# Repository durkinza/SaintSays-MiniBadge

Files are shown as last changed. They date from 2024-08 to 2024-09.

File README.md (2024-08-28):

# SAINTSays Mini-Badge

<span style="font-size:0.8em;font-style:italic;">This badge is not made in affiliation with or endorced by the SAINTCON conference or the Utah SAINT organization</span>

This was my first time designing and producing a minibadge for SAINTCON (2024), so it may be a bit rough around the edges.

This repo contains the Code and KiCad file for the SAINTSays Mini-Badge.

## Programming the Badge

Compiling the code in the Arduino IDE for an ATTINY requires a package that supports the `Wire.h` library.

I found that the [ATTINYCore](https://github.com/SpenceKonde/ATTinyCore/blob/v2.0.0-devThis-is-the-head-submit-PRs-against-this/Installation.md) library works well for this. 
If you don't plan on using the I2C features, The [attiny](https://github.com/damellis/attiny) package can also be used for programming the badge. 

The badge has the AREF pins connected to the Mini-Badge headers using the [suggested connection method](https://github.com/lukejenkins/minibadge#prog): 

| Header| Pin |
|---|---|
| MISO  | Pin 3 |
| CLK | Pin 4 |
| MOSI  | Pin 5 |
| RESET | Pin 6 |

The power pin is wired to the 3.3v supply on Pin 7 and ground on Pin 8.

The Clock and SDA/SCL pins are also connected to the ATTiny. 
Be sure these Headers are not connected to external things when programming the badge. 

## Disabling I2C
If you don't plan on using the I2C features of the badbge, the code can be removed by commenting out the `#define USEI2C true` line near the top of the .ino file. 
This has the added benefit of making the compiled code a fair bit smaller too.

## Documentation

[How to solder the badge](https://zanedurk.in/soldering-the-saintsays-mini-badge/)

[How it's made](https://zanedurk.in/saintsays-mini-badge/)

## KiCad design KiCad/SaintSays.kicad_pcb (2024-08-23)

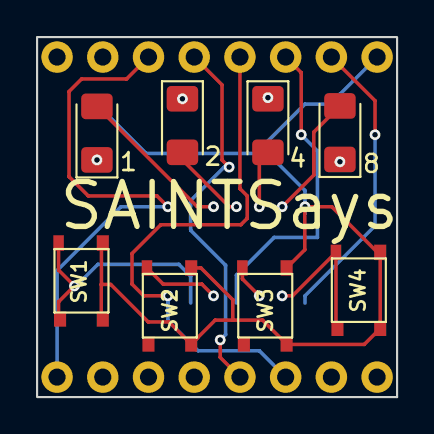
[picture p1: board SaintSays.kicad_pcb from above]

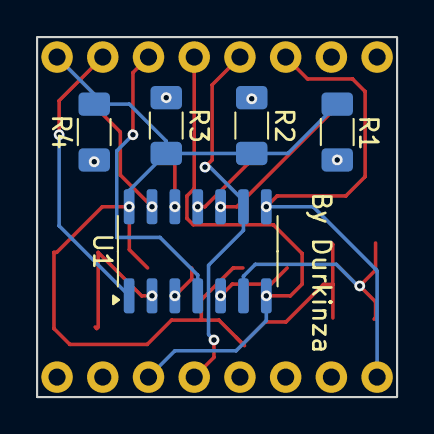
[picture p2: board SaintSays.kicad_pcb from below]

Board: 2 copper layers, 20.0 x 20.0 mm, 14 parts (5 on the bottom side), 18 nets.

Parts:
1, 2, 4, 8: LED; LED_1206_3216Metric_Pad1.42x1.75mm_HandSolder
MB1: MiniBadge_SAINTSays; MiniBadge_Full
R1, R2, R3, R4: R_US; R_1206_3216Metric_Pad1.30x1.75mm_HandSolder
SW1, SW2, SW3, SW4: SW_Push; SW_SPST_3x3-L
U1: ATtiny84A-SS; SOIC-14_3.9x8.7mm_P1.27mm

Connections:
unnamed: 1.2 (A), U1.10 (PA3)
unnamed: 1.1 (K), R1.1
unnamed: 2.2 (A), U1.11 (PA2)
unnamed: 2.1 (K), R2.1
unnamed: 4.2 (A), U1.12 (PA1)
unnamed: 4.1 (K), R3.1
unnamed: 8.2 (A), U1.13 (AREF/PA0)
unnamed: 8.1 (K), R4.1
unnamed: MB1.7 (+3V3), U1.1 (VCC)
unnamed: MB1.3 (MISO), MB1.9 (CLK), U1.8 (PA5)
unnamed: MB1.6 (CS), U1.4 (~RESET/PB3)
unnamed: MB1.5 (MOSI), MB1.14 (SDA), U1.7 (PA6)
unnamed: MB1.4 (SCK), MB1.13 (SCL), U1.9 (PA4)
unnamed: MB1.8 (GND), R1.2, R2.2, R3.2, R4.2, SW1.2, SW2.2, SW3.2, SW4.2, U1.14 (GND)
unnamed: SW1.1, U1.6 (PA7)
unnamed: SW2.1, U1.5 (PB2)
unnamed: SW4.1, U1.2 (XTAL1/PB0)
unnamed: SW3.1, U1.3 (XTAL2/PB1)

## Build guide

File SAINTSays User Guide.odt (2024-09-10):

SAINTSays By Durkinza | MODES The Badge has 4 modes: Sleep, Game, Settings, and Party When first booted, the badge goes into Sleep Mode. | SLEEP MODE Sleep Mode is the default mode of this badge. After your first game, this mode will display your score in binary on the LEDs (in Little Endian). (A new badge will have a score of 0, so no LEDS on)
GAME MODE Game Mode can be entered by pushing any individual button while in Sleep Mode. Press the outside buttons simultaneously to return to Sleep Mode. If nothing is pressed for 60 seconds, the badge will return to Sleep Mode. | GAME MODE Cont’d. The game is Simon Says, where the badge will flash a pattern of LEDs and wait for you to repeat the pattern. Each successful round will increase the pattern's length. When an incorrect pattern is entered, the badge will flash. If you get a new high score, the badge will save this locally to its EEPROM. | SETTINGS MODE To enter Settings Mode, press the outside buttons simultaneously while in Sleep Mode. Do this again to return to Sleep Mode. There are 4 settings that can be toggled: 1: Show scoreboard in Sleep Mode. 2: ! Fast Mode. (Light speed) 3: ! Chaotic Mode (Hard Mode; no repetitions) 4: ! Boot to Party Mode

SAINTSays By Durkinza | MODES The Badge has 4 modes: Sleep, Game, Settings, and Party When first booted, the badge goes into Sleep Mode. | SLEEP MODE Sleep Mode is the default mode of this badge. After your first game, this mode will display your score in binary on the LEDs (in Little Endian). (A new badge will have a score of 0, so no LEDS on)
GAME MODE Game Mode can be entered by pushing any individual button while in Sleep Mode. Press the outside buttons simultaneously to return to Sleep Mode. If nothing is pressed for 60 seconds, the badge will return to Sleep Mode. | GAME MODE Cont’d. The game is Simon Says, where the badge will flash a pattern of LEDs and wait for you to repeat the pattern. Each successful round will increase the pattern's length. When an incorrect pattern is entered, the badge will flash. If you get a new high score, the badge will save this locally to its EEPROM. | SETTINGS MODE To enter Settings Mode, press the outside buttons simultaneously while in Sleep Mode. Do this again to return to Sleep Mode. There are 4 settings that can be toggled: 1: Show scoreboard in Sleep Mode. 2: ! Fast Mode. (Light speed) 3: ! Chaotic Mode (Hard Mode; no repetitions) 4: ! Boot to Party Mode

SAINTSays By Durkinza | MODES The Badge has 4 modes: Sleep, Game, Settings, and Party When first booted, the badge goes into Sleep Mode. | SLEEP MODE Sleep Mode is the default mode of this badge. After your first game, this mode will display your score in binary on the LEDs (in Little Endian). (A new badge will have a score of 0, so no LEDS on)
GAME MODE Game Mode can be entered by pushing any individual button while in Sleep Mode. Press the outside buttons simultaneously to return to Sleep Mode. If nothing is pressed for 60 seconds, the badge will return to Sleep Mode. | GAME MODE Cont’d. The game is Simon Says, where the badge will flash a pattern of LEDs and wait for you to repeat the pattern. Each successful round will increase the pattern's length. When an incorrect pattern is entered, the badge will flash. If you get a new high score, the badge will save this locally to its EEPROM. | SETTINGS MODE To enter Settings Mode, press the outside buttons simultaneously while in Sleep Mode. Do this again to return to Sleep Mode. There are 4 settings that can be toggled: 1: Show scoreboard in Sleep Mode. 2: ! Fast Mode. (Light speed) 3: ! Chaotic Mode (Hard Mode; no repetitions) 4: ! Boot to Party Mode

SETTINGS MODE Cont’d. Each LED represents a setting and lights up when the corresponding setting is enabled. Pressing the button below each LED will toggle the corresponding setting. Settings are saved when you leave Setting Mode. | PARTY MODE Party mode can be entered by pressing both inside buttons (2,3) while in the Sleep Mode Press the outside buttons simultaneously to return to Sleep Mode. | RESETTING THE BADGE To reset your high score and settings, the badge can be “factory reset”. This will set the high score to 0 and default all other settings. While in Sleep Mode, hold all 4 buttons for 10 seconds (until the lights flash) to reset the EEPROM.
I2C (if enabled) This badge will listen to the I2C bus as device 0x23 (configurable in code). | Additional Info For Code and KiCad files checkout the GitHub Repo: https://github.com/durkinza/SaintSays-MiniBadge For Soldering steps checkout: https://zanedurk.in/soldering-the-saintsays-mini-badge/ For a how it’s made checkout: https://zanedurk.in/saintsays-mini-badge/ | GitHub Soldering Steps

SETTINGS MODE Cont’d. Each LED represents a setting and lights up when the corresponding setting is enabled. Pressing the button below each LED will toggle the corresponding setting. Settings are saved when you leave Setting Mode. Soldering Steps | PARTY MODE Party mode can be entered by pressing both inside buttons (2,3) while in the Sleep Mode Press the outside buttons simultaneously to return to Sleep Mode. | RESETTING THE BADGE To reset your high score and settings, the badge can be “factory reset”. This will set the high score to 0 and default all other settings. While in Sleep Mode, hold all 4 buttons for 10 seconds (until the lights flash) to reset the EEPROM.
I2C (if enabled) This badge will listen to the I2C bus as device 0x23 (configurable in code). | Additional Info For Code and KiCad files checkout the GitHub Repo: https://github.com/durkinza/SaintSays-MiniBadge For Soldering steps checkout: https://zanedurk.in/soldering-the-saintsays-mini-badge/ For a how it’s made checkout: https://zanedurk.in/saintsays-mini-badge/ | GitHub

SETTINGS MODE Cont’d. Each LED represents a setting and lights up when the corresponding setting is enabled. Pressing the button below each LED will toggle the corresponding setting. Settings are saved when you leave Setting Mode. | PARTY MODE Party mode can be entered by pressing both inside buttons (2,3) while in the Sleep Mode Press the outside buttons simultaneously to return to Sleep Mode. | RESETTING THE BADGE To reset your high score and settings, the badge can be “factory reset”. This will set the high score to 0 and default all other settings. While in Sleep Mode, hold all 4 buttons for 10 seconds (until the lights flash) to reset the EEPROM.
I2C (if enabled) This badge will listen to the I2C bus as device 0x23 (configurable in code). | Additional Info For Code and KiCad files checkout the GitHub Repo: https://github.com/durkinza/SaintSays-MiniBadge For Soldering steps checkout: https://zanedurk.in/soldering-the-saintsays-mini-badge/ For a how it’s made checkout: https://zanedurk.in/saintsays-mini-badge/ | Soldering Steps GitHub

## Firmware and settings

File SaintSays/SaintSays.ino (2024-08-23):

// The I2C bus allows the Main badge to communicate with this minibadge 
// to pull/set settings, high scores, etc.
#define USEI2C true

// Using the EEPROM allows the badge to retain highscore and settings when powered off. 
#define USEEEPROM true

// Checks for certain compiler packages.
#ifdef PINMAPPING_CCW
#error "Sketch was written for clockwise pin mapping!"
#endif


/*******************************
******* GENERAL SETTINGS *******
********************************/
// Pin definitions
#define BUTTONCOUNT 4
#define LEDCOUNT 4
// const uint8_t ledPins[LEDCOUNT] = {10, 9, 8, 7}; // LED pins (v1,v2 minibadge only)
// const uint8_t buttonPins[BUTTONCOUNT] = {1, 2, 3, 4}; // Button pins (v1,v2 minibadge only)
// const uint8_t ledPins[LEDCOUNT] = {10, 11, 12, 13}; // LED pins (v3+ minibadge)
const uint8_t ledPins[LEDCOUNT] = {3, 2, 1, 0}; // LED pins (v3+ minibadge)
const uint8_t buttonPins[BUTTONCOUNT] = {7, 8, 9, 10}; // Button pins (v3+ minibadge)
const uint8_t clockPin = 5; // Clock Sensing pin. (v3+ minibadge)

// Variables for menu settings
#define SETTINGSCOUNT 4 // Settings count should always be <= button and LED counts, and should never exceed 8.
bool settings[SETTINGSCOUNT] = {true, true, true, true}; // {showScoreWhileAsleep, (non)FastMode, (non)ChaoticMode, PartyModeOnBoot }
bool buttonsPressed[BUTTONCOUNT] = {false, false, false, false}; // Buttons Pressed State.

// Variables for transitions and debounce
const unsigned int loopDelay = 200; // Give users time to press buttons between loops
const unsigned long resetholdTime = 10000; // 10 seconds in milliseconds
const unsigned long gameTimeout = 60000;  // Wait 1 minute for a button to be pressed.

// Track highest score
volatile uint32_t highScore = 0;

// Variables for game state
uint8_t pattern[24]; // Max pattern length (Should this be longer than 16?)
uint8_t patternLength = 0; // Current pattern Index (a.k.a current score)
int patternPulseSlow = 500; // How long to show each pattern step for.
int patternPulseQuick = 100; // How long to show each pattern step for.


// Tracking the current mode the badge is in. 
enum Modes {SLEEPMODE, SETTINGSMODE, GAMEMODE, LIGHTSHOWMODE}; 
Modes mode = SLEEPMODE;


#ifdef USEEEPROM
/*******************************
********** EEPROM **************
********************************/
#include <EEPROM.h>
// EEPROM address for high score
const uint8_t EEPROMhighScoreAddress = 0;
const uint8_t EEPROMsettingsAddress = 8;
#endif

#ifdef USEI2C
/*******************************
************ I2C ***************
********************************/
// Note that the ATTiny Core's implmentation of wire.h is used
// ref: https://github.com/SpenceKonde/ATTinyCore/blob/v2.0.0-devThis-is-the-head-submit-PRs-against-this/avr/libraries/Wire/src/Wire.h
// ref: https://github.com/lukejenkins/minibadge/blob/master/I2C%20Example%20Code/Minibadge_sample_code.ino
#include <Wire.h>
#define I2C_DEVICE_ADDR 0x23 // I2C address for this device
uint8_t I2C_WRITE_SUPPORT = 1; // Set to 1 to enable Writing Score and settings
// Writing Actions:
#define I2C_WRITE_SCORE 0
#define I2C_WRITE_SETTING_1 1
#define I2C_WRITE_SETTING_2 2
#define I2C_WRITE_SETTING_3 3
#define I2C_WRITE_SETTING_4 4
#define I2C_WRITE_BRIGHTNESS 5
// Reading Actions:
#define I2C_READ_NOP 0 // No operation
#define I2C_READ_BUTTON 1 // toggling button
#define I2C_READ_SCORE 2 // Reading High Score
// #define I2C_READ_SETTING_1 20 // Reading Setting 1
// #define I2C_READ_SETTING_2 30 // Reading Setting 2
// #define I2C_READ_SETTING_3 40 // Reading Setting 3
// #define I2C_READ_SETTING_4 50 // Reading Setting a4
// #define I2C_READ_BRIGHTNESS 60 // Reading LED Brightness
uint8_t i2cReadAction = I2C_READ_SCORE;


// Any variable being writen to inside an interupt Ie. request() or recieve() should be volatile.
// These are default values and will change as the badge talks to the minibadge.
// enum ReadStates { I2C_STATE_NOP, RespondWrite, RespondRead, ReadPartTwo, ReadPartThree };
// #define I2C_STATE_NOP 0
// #define I2C_STATE_WRITE 1
// #define I2C_STATE_READ 2
// #define I2C_STATE_READ_PT2 3 // Rading High Score
// #define I2C_STATE_READ_PT3 4 // Rading High Score

enum ReadStates { I2C_STATE_NOP, I2C_STATE_WRITE, I2C_STATE_READ, I2C_STATE_READ_PT2, I2C_STATE_READ_PT3 };
volatile ReadStates i2cState = I2C_STATE_NOP;
// volatile ReadStates reading_state = I2C_STATE_NOP; // this should only be set to RespondWrite or RespondRead in the recieve function.
volatile uint8_t brightness = 100;
#endif

void setup() {
  // Initialize LEDs as outputs
  for (uint8_t i = 0; i < LEDCOUNT; i++) {
    pinMode(ledPins[i], OUTPUT);
  }
  for (uint8_t i = 0; i < LEDCOUNT; i++) {
    digitalWrite(ledPins[i], LOW);
  }
  // Initialize buttons as inputs with pull-up resistors
  for (uint8_t i = 0; i < BUTTONCOUNT; i++) {
    pinMode(buttonPins[i], INPUT_PULLUP);
  }
  
  pinMode(clockPin, INPUT);

#ifdef USEEEPROM
  // Load the high score and settings from EEPROM.
  readHighScoreFromEEPROM();
  readSettingsFromEEPROM();
#else
  // Set default highscore and settings.
  highScore = 1;
  // memcpy(settings, defaultsettings, SETTINGSCOUNT);
#endif

#ifdef USEI2C
  // Share score on I2C bus
  Wire.onRequest(RequestI2CEvent); // Register event handler for I2C Request events
  Wire.onReceive(RecieveI2CEvent); // Register event handler for I2C Recieve events
  Wire.begin(I2C_DEVICE_ADDR); // Join I2C bus with the given address
#else
  // Set I2C pins to read so they do not interfere with the rest of the bus
  // Pins 6&5 for the ATTINY84a.
  pinMode(6, INPUT); // SDA
  pinMode(5, INPUT); // SCL
#endif

  // Show Startup Sequence
  showStartup();

  // Set initial state
  if(settings[3]){
    mode = SLEEPMODE;
  }else{
    mode = LIGHTSHOWMODE;
  }
}

void loop() {
  Modes starting_mode = mode;
  checkButtonsPressed();
  if(mode == SLEEPMODE){
    handleSleepMode();
  }else if(mode == SETTINGSMODE){
    handleSettingsMode();
  }else if(mode == LIGHTSHOWMODE){
    handleLightShowMode();
  }else if (mode == GAMEMODE) {
    handleGameMode();
  }
  delay(loopDelay);
  // If we are going to sleep mode from another mode, play a sweep.
  if((mode == SLEEPMODE) & (starting_mode != mode)){
    showSweep2();
  }
}


/*******************************
*********** HANDLERS ***********
*******************************/
void handleSleepMode(){
  //Check if a reset is happening
  if(allButtonsPressed()){
    handleResetTimer();
    return;
  }else if(outsideButtonsPressed()){
    mode = SETTINGSMODE;
    return;
  }else if(insideButtonsPressed()){
    mode = LIGHTSHOWMODE;
    return;
  }else if(anyButtonsPressed()){
    mode = GAMEMODE;
    return;
  }else{
    // Check if we should display score in sleep mode;
    if(settings[0]){
      displayHighScore();
    }else{
      // Turn off LEDs if in sleep mode
      for (uint8_t i = 0; i < LEDCOUNT; i++) {
        digitalWrite(ledPins[i], LOW);
      }
    }
  }
  delay(loopDelay);
}

void handleSettingsMode(){
  showSweep(); // Give user time to release side buttons.
  while(true){
    displaySettings();
    checkButtonsPressed();
    if(outsideButtonsPressed()){
      break;
    }else{
      for(uint8_t i = 0; i < SETTINGSCOUNT; i++){
        if(buttonsPressed[i]){
          settings[i] = !settings[i];
        }
      }
    }
    delay(loopDelay);
  }
  #ifdef USEEEPROM
  saveSettingsToEEPROM();
  #endif
  mode = SLEEPMODE;
  delay(loopDelay);
}

void handleGameMode(){
  // Clear last Game
  memset(pattern, 0, sizeof(pattern));
  patternLength = 0;
  // randomSeed(analogRead(unconnectedPin));
  randomSeed(micros());

  // Turn off all LEDs
  turnOffLights();

  while(true){
      if(!settings[2]){
        // if Chaotic Mode, build a new pattern each time.
        for(uint8_t i = 0; i <= patternLength; i++){
          pattern[i] = (uint8_t)random(0, 4); // from 1 to 4;
        }
      }else{
        // When not in Chatoic Mode, just add a new value to the end of the pattern
        pattern[patternLength] = (uint8_t)random(0, 4); // from 1 to 4;
      }
      flashPattern();
      // Have user input all parts of pattern.
      for(uint8_t patternIndex=0; patternIndex < patternLength; patternIndex++){
          // loop forever while waiting for user to press a button
          unsigned long lastButtonTime = millis();
          while(true){
              checkButtonsPressed();
              if(outsideButtonsPressed()){
                  // If both outside buttons are pressed, leave game.
                  mode = SLEEPMODE;
                  return;
              }
              if(millis() - lastButtonTime > gameTimeout){
                  // If no buttons have been pressed, return to Sleep.
                  mode = SLEEPMODE;
                  return;
              }
              if(anyButtonsPressed()){
                  // Flash LED for pressed buttons
                  for(uint8_t i=0; i < BUTTONCOUNT; i++){
                      if(buttonsPressed[i]){
                          digitalWrite(ledPins[i], HIGH);
                      }
                  }
                  delay(200); // let the user see the light they pressed.
                  turnOffLights();
                  // Done flashing.
                  // Now check Pattern.
                  if(!checkPatternMatch(patternIndex)) {
                      // failed check, 
                      // Save scoe and exit.
                      if(highScore < patternLength){
                        highScore = patternLength;
                      }
                      #ifdef USEEEPROM
                      saveHighScoreToEEPROM();
                      #endif
                      flashFailedPattern();
                      mode = SLEEPMODE;
                      // Leave GameMODE;
                      return;
                  }
                  //check passed, break out of while loop to for loop
                  break;
              }
              delay(loopDelay);
          }
          // Wait for user to let go of button
          while(anyButtonsPressed()){
              checkButtonsPressed();
          }
      }
      // If the user got the pattern correct, 
      // Increment index and loop.
      patternLength++;
      // Give the user time to expect the next pattern.
      delay(1000);
  }
}

void handleResetTimer(){
  unsigned long startTime = millis();
  while(true){
    checkButtonsPressed();
    if(!allButtonsPressed()){
      mode = SLEEPMODE;
      // If buttons are released, leave reset Timer.
      return;
    }
    if(millis() - startTime >= resetholdTime){
      // Onces we're out of time, break the loop
      break;
    }
  }
  showClearing();
  // Reset Settings to Default.
  settings[0] = true;
  settings[1] = true;
  settings[2] = true;
  settings[3] = true;
  highScore = 0;

  #ifdef USEEEPROM
  saveSettingsToEEPROM();
  EEPROM.write(EEPROMhighScoreAddress, 0);
  #endif
  mode = SLEEPMODE;
  delay(loopDelay);
}

void handleLightShowMode(){
  turnOffLights();
  // Do cool light patterns to make brain happy!
  uint8_t LS_index = 0; // which pattern are we doing
  while(true){
    LS_index = random(0,4);
    checkButtonsPressed();
    if(outsideButtonsPressed()){
        // If both outside buttons are pressed, leave to sleepmode.
        mode = SLEEPMODE;
        // Wait for user to let go of button
        while(anyButtonsPressed()){
            checkButtonsPressed();
        }
        return;
    }
    switch(LS_index){
      case 0:
        lightShowPattern1();
        break;
      case 1:
        lightShowPattern2();
        break;
      case 2:
        lightShowPattern3();
        break;
      case 3:
        lightShowPattern4();
        break;
    }
    delay(loopDelay);
  }
}

/*******************************
******** BUTTON HELPERS ********
*******************************/
void checkButtonsPressed(){
  for (uint8_t i = 0; i < BUTTONCOUNT; i++) {
    buttonsPressed[i] = (digitalRead(buttonPins[i]) == LOW);
  }
}
bool allButtonsPressed(){
  bool result = true;
  for (uint8_t i = 0; i < BUTTONCOUNT; i++) {
    if(!buttonsPressed[i]){
      result = false;
    }
  }
  return result;
}
bool outsideButtonsPressed(){
  bool result = true;
  if(!buttonsPressed[0]){
    result = false;
  }
  if(!buttonsPressed[BUTTONCOUNT-1]){
    result = false;
  }
  return result;
}
bool insideButtonsPressed(){
  bool result = true;
  for(uint8_t i =1; i < BUTTONCOUNT-1; i++){
    if(!buttonsPressed[i]){
      result = false;
    }
  }
  return result;
}
bool anyButtonsPressed(){
  bool result = false;
  for (uint8_t i = 0; i < BUTTONCOUNT; i++) {
    if(buttonsPressed[i]){
      result = true;
    }
  }
  return result;
}

bool checkPatternMatch(uint8_t patternIndex){
  // Check if user pressed the correct button in the current place in the pattern.
  bool pressedCorrect = false;
  bool pressedExtra = false;
  for (uint8_t i = 0; i < BUTTONCOUNT; i++) {
    if(pattern[patternIndex] == i){
      if(buttonsPressed[i]){
        pressedCorrect = true;
      }
    }else{
      if(buttonsPressed[i]){
        pressedExtra = true;
      }
    }
  }
  return (pressedCorrect & !pressedExtra);
}

/*******************************
********* LED HELPERS **********
*******************************/
void turnOffLights(){
  for(uint8_t i = 0; i < LEDCOUNT; i++){
      digitalWrite(ledPins[i], LOW);
  }
}
void flashPattern(){
  int patternPulse = settings[1] ? patternPulseSlow:patternPulseQuick;
  for (uint8_t i = 0; i < patternLength; i++) {
      digitalWrite(ledPins[pattern[i]], HIGH);
      delay(patternPulse);
      digitalWrite(ledPins[pattern[i]], LOW);
      delay(patternPulse);
  }
}

void flashFailedPattern(){
  for(uint8_t j = 0; j<2; j++){
    for(uint8_t i = 0; i<LEDCOUNT; i++){
      digitalWrite(ledPins[i], HIGH);
    }
    delay(500);
    for(uint8_t i = 0; i<LEDCOUNT; i++){
      digitalWrite(ledPins[i], LOW);
    }
    delay(500);
  }
}


void displayHighScore(){
  //TODO If Score is >16, then just show all lights on.
  // Alternatative: flash throught the full byte?
  uint32_t score = highScore;
  if (highScore >= 16){
    score = 0xFF;
  }
  for (uint8_t i = 0; i < LEDCOUNT; i++) {
    if (score & (1 << i)) {
      digitalWrite(ledPins[i], HIGH);
    } else {
      digitalWrite(ledPins[i], LOW);
    }
  }
}

void displaySettings(){
  for (uint8_t i = 0; i < SETTINGSCOUNT; i++) {
    if(settings[i]){
      digitalWrite(ledPins[i], HIGH);
    } else {
      digitalWrite(ledPins[i], LOW);
    }
  }
}

void showSweep(){
  turnOffLights();
  // Show a cool Sweep sequence in the LEDs
  digitalWrite(ledPins[0], HIGH);
  delay(200);
  digitalWrite(ledPins[1], HIGH);
  delay(200);
  digitalWrite(ledPins[2], HIGH);
  delay(200);
  digitalWrite(ledPins[3], HIGH);
  delay(200);
  digitalWrite(ledPins[0], LOW);
  delay(200);
  digitalWrite(ledPins[1], LOW);
  delay(200);
  digitalWrite(ledPins[2], LOW);
  delay(200);
  digitalWrite(ledPins[3], LOW);
}
void showSweep2(){
  turnOffLights();
  // Show a cool Sweep sequence in the LEDs
  digitalWrite(ledPins[0], HIGH);
  digitalWrite(ledPins[3], HIGH);
  delay(200);
  digitalWrite(ledPins[2], HIGH);
  digitalWrite(ledPins[1], HIGH);
  delay(200);
  digitalWrite(ledPins[0], LOW);
  digitalWrite(ledPins[3], LOW);
  delay(200);
  digitalWrite(ledPins[2], LOW);
  digitalWrite(ledPins[1], LOW);
}

void showStartup(){
  // Show a cool startup sequence in the LEDs
  digitalWrite(ledPins[0], HIGH);
  delay(200);
  digitalWrite(ledPins[3], HIGH);
  delay(200);
  digitalWrite(ledPins[1], HIGH);
  delay(200);
  digitalWrite(ledPins[2], HIGH);
  delay(200);
  digitalWrite(ledPins[0], LOW);
  delay(200);
  digitalWrite(ledPins[3], LOW);
  delay(200);
  digitalWrite(ledPins[1], LOW);
  delay(200);
  digitalWrite(ledPins[2], LOW);
}
void showClearing(){
  turnOffLights();
  // Show a cool Sweep sequence in the LEDs
  digitalWrite(ledPins[0], HIGH);
  digitalWrite(ledPins[3], HIGH);
  digitalWrite(ledPins[2], HIGH);
  digitalWrite(ledPins[1], HIGH);
  delay(100);
  digitalWrite(ledPins[0], LOW);
  digitalWrite(ledPins[3], LOW);
  digitalWrite(ledPins[2], LOW);
  digitalWrite(ledPins[1], LOW);
  delay(100);
  digitalWrite(ledPins[0], HIGH);
  digitalWrite(ledPins[3], HIGH);
  digitalWrite(ledPins[2], HIGH);
  digitalWrite(ledPins[1], HIGH);
  delay(100);
  digitalWrite(ledPins[0], LOW);
  digitalWrite(ledPins[3], LOW);
  digitalWrite(ledPins[2], LOW);
  digitalWrite(ledPins[1], LOW);
  delay(100);
  digitalWrite(ledPins[0], HIGH);
  digitalWrite(ledPins[3], HIGH);
  digitalWrite(ledPins[2], HIGH);
  digitalWrite(ledPins[1], HIGH);
  delay(100);
  digitalWrite(ledPins[0], LOW);
  digitalWrite(ledPins[3], LOW);
  digitalWrite(ledPins[2], LOW);
  digitalWrite(ledPins[1], LOW);
  delay(100);
  digitalWrite(ledPins[0], HIGH);
  digitalWrite(ledPins[3], HIGH);
  digitalWrite(ledPins[2], HIGH);
  digitalWrite(ledPins[1], HIGH);
  delay(700);
  digitalWrite(ledPins[0], LOW);
  digitalWrite(ledPins[3], LOW);
  digitalWrite(ledPins[2], LOW);
  digitalWrite(ledPins[1], LOW);
}

void lightShowPattern1(){
// void lightShowPattern1(uint8_t sweeps = 2){
  uint8_t sweeps = 2;
  // night rider
  for(uint8_t i = 0; i < sweeps; i++){
    // Show a cool Sweep sequence in the LEDs
    digitalWrite(ledPins[0], HIGH);
    delay(200);
    digitalWrite(ledPins[0], LOW);
    digitalWrite(ledPins[1], HIGH);
    delay(200);
    digitalWrite(ledPins[1], LOW);
    digitalWrite(ledPins[2], HIGH);
    delay(200);
    digitalWrite(ledPins[2], LOW);
    digitalWrite(ledPins[3], HIGH);
    delay(200);
    digitalWrite(ledPins[3], LOW);
    digitalWrite(ledPins[2], HIGH);
    delay(200);
    digitalWrite(ledPins[2], LOW);
    digitalWrite(ledPins[1], HIGH);
    delay(200);
    digitalWrite(ledPins[1], LOW);
    digitalWrite(ledPins[0], HIGH);
    delay(200);
    digitalWrite(ledPins[0], LOW);
  }
}

void lightShowPattern2(){
// void lightShowPattern2(uint8_t flashes = 20);
// void lightShowPattern2(uint8_t flashes = 20, uint8_t flash_delay = 100){
  uint8_t flashes = 10;
  uint8_t flash_delay = 200;

  // random
  uint8_t led = 0;
  for(uint8_t i = 0; i < flashes; i++){
    led = random(0,4); // Pick a random LED
    digitalWrite(ledPins[led], HIGH);
    delay(flash_delay);
    digitalWrite(ledPins[led], LOW);
  }
}
void lightShowPattern3(){
  // out to in
  uint8_t loops = 3;
  for(uint8_t i = 0; i < loops; i++){
    //outside flash
    digitalWrite(ledPins[0], HIGH);
    digitalWrite(ledPins[LEDCOUNT-1], HIGH);
    delay(200);
    digitalWrite(ledPins[0], LOW);
    digitalWrite(ledPins[LEDCOUNT-1], LOW);
    delay(200);
    digitalWrite(ledPins[0], HIGH);
    digitalWrite(ledPins[LEDCOUNT-1], HIGH);
    delay(200);
    digitalWrite(ledPins[0], LOW);
    digitalWrite(ledPins[LEDCOUNT-1], LOW);
    //inside flash
    digitalWrite(ledPins[1], HIGH);
    digitalWrite(ledPins[LEDCOUNT-2], HIGH);
    delay(200);
    digitalWrite(ledPins[1], LOW);
    digitalWrite(ledPins[LEDCOUNT-2], LOW);
    delay(200);
    digitalWrite(ledPins[1], HIGH);
    digitalWrite(ledPins[LEDCOUNT-2], HIGH);
    delay(200);
    digitalWrite(ledPins[1], LOW);
    digitalWrite(ledPins[LEDCOUNT-2], LOW);
  }
}
void lightShowPattern4(){
  // every other flash
  uint8_t loops = 3;
  for(uint8_t i = 0; i < loops; i++){
    //odd flash
    digitalWrite(ledPins[0], HIGH);
    digitalWrite(ledPins[LEDCOUNT-2], HIGH);
    delay(200);
    digitalWrite(ledPins[0], LOW);
    digitalWrite(ledPins[LEDCOUNT-2], LOW);
    delay(200);
    digitalWrite(ledPins[0], HIGH);
    digitalWrite(ledPins[LEDCOUNT-2], HIGH);
    delay(200);
    digitalWrite(ledPins[0], LOW);
    digitalWrite(ledPins[LEDCOUNT-2], LOW);
    //even flash
    digitalWrite(ledPins[1], HIGH);
    digitalWrite(ledPins[LEDCOUNT-1], HIGH);
    delay(200);
    digitalWrite(ledPins[1], LOW);
    digitalWrite(ledPins[LEDCOUNT-1], LOW);
    delay(200);
    digitalWrite(ledPins[1], HIGH);
    digitalWrite(ledPins[LEDCOUNT-1], HIGH);
    delay(200);
    digitalWrite(ledPins[1], LOW);
    digitalWrite(ledPins[LEDCOUNT-1], LOW);
  }
}



#ifdef USEEEPROM
/*******************************
******* EEPROM HELPERS *********
*******************************/
void saveHighScoreToEEPROM(){
    // Read in current Settings for comparison.
  uint8_t StoredHighScore = EEPROM.read(EEPROMhighScoreAddress);
  // Avoid extra uneccessary writes to EEPROM.
  if(StoredHighScore < highScore){
    EEPROM.write(EEPROMhighScoreAddress, highScore);
  }
}
void readHighScoreFromEEPROM(){
    // Read in current Settings for comparison.
  highScore = EEPROM.read(EEPROMhighScoreAddress);
  if(highScore > sizeof(pattern)){
    // EEPROM is default to all 1s, so set it back to zero.
    highScore = 0;
    EEPROM.write(EEPROMhighScoreAddress, 0);
  }
}

void saveSettingsToEEPROM() {
  // Pack settings into a single Byte.
  byte packedByte = 0;
  for (uint8_t i = 0; i < SETTINGSCOUNT; i++) {
    if (settings[i]) {
      packedByte |= (1 << i);
    }
  }
  // Read in current Settings for comparison.
  byte storedByte = EEPROM.read(EEPROMsettingsAddress);
  // Avoid extra uneccessary writes to EEPROM.
  if(storedByte != packedByte){
    EEPROM.write(EEPROMsettingsAddress, packedByte);
  }
}

void readSettingsFromEEPROM() {
  byte packedByte = EEPROM.read(EEPROMsettingsAddress);
  for (uint8_t i = 0; i < SETTINGSCOUNT; i++) {
    settings[i] = (packedByte & (1 << i)) != 0;
  }
}
#endif
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

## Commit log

2024-08-23 Adding V3 code and KiCad
    [SaintSays-B_Cu.gbl, SaintSays-B_Mask.gbs, SaintSays-B_Paste.gbp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]
2024-08-23 adding some updates, still working on I2C communication.
